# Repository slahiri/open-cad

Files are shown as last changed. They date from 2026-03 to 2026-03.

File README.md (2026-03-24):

# Protective Storage Box — Pelican/Gun Case Style

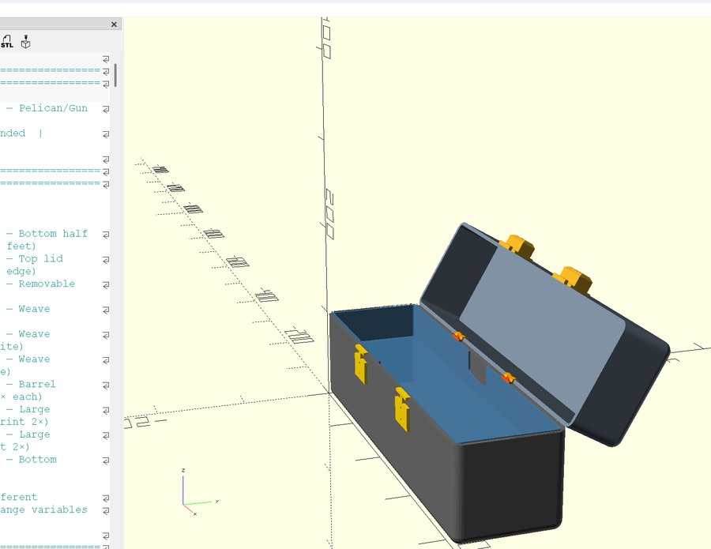
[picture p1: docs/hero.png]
Protective Storage Box


A 3D-printable protective storage box designed in OpenSCAD. Features a clamshell design with barrel hinges, butterfly latches, removable compartmented tray, and snap-fit 3-piece construction for printers with beds smaller than 420mm.

## Specifications

| Parameter | Value |
|---|---|
| Outer Dimensions | 420 x 110 x 160 mm |
| Wall Thickness | 4 mm |
| Bottom Height | 100 mm |
| Lid Height | 60 mm |
| Corner Radius | 10 mm (3D filleted) |
| Material | PETG recommended |

## Features

- Clamshell opening with 2 barrel hinges (M3 pin)
- 2 butterfly clamp latches (gun-box style)
- Removable interior tray (40mm) with finger notches
- Tray support ledge inside box walls
- Basket-weave lid insert (multi-color: white + blue)
- Gasket groove for weatherproofing (1mm silicone cord)
- 6 standoff feet with rubber pad recesses
- Split parts for printers with <420mm bed (e.g. Creality K2 Plus)

## Project Structure

```
open-cad/
  README.md
  .gitignore
  cad/                          # OpenSCAD source files
    protective_storage_box.scad   # Main library (all modules)
    view_closed.scad              # Assembly view: closed
    view_open.scad                # Assembly view: lid open
    view_open_tray_out.scad       # Assembly view: lid open, tray lifted
    stl_bottom_left.scad          # Export: box bottom left half
    stl_bottom_right.scad         # Export: box bottom right half
    stl_lid_left.scad             # Export: lid left half
    stl_lid_right.scad            # Export: lid right half
    stl_tray_left.scad            # Export: tray left half
    stl_tray_right.scad           # Export: tray right half
    stl_weave_frame_left.scad     # Export: weave frame left half
    stl_weave_frame_right.scad    # Export: weave frame right half
    stl_weave_x_left.scad         # Export: weave X-strips left (white)
    stl_weave_x_right.scad        # Export: weave X-strips right (white)
    stl_weave_y_left.scad         # Export: weave Y-strips left (blue)
    stl_weave_y_right.scad        # Export: weave Y-strips right (blue)
    stl_all_hardware.scad         # Export: hinges + latches on one plate
    export_k2plus.scad            # K2 Plus printing guide
    export_parts.scad             # Generic export guide
  stl/                          # Generated STL files (gitignored)
```

## How to Export STLs

Each `cad/stl_*.scad` file contains exactly one part. For each:

1. Open the file in OpenSCAD
2. **Design -> Render**
3. **File -> Export -> Export as STL**

## Print Settings (PETG)

| Part | Qty | Infill | Walls | Supports | Filament |
|---|---|---|---|---|---|
| Bottom L/R | 2 | 40% | 4 | No | Dark Gray |
| Lid L/R | 2 | 40% | 4 | No | Dark Gray |
| Tray L/R | 2 | 20% | 3 | No | Blue |
| Weave Frame L/R | 2 | 100% | 3 | No | Dark Gray |
| Weave X-strips L/R | 2 | 100% | 3 | No | White |
| Weave Y-strips L/R | 2 | 100% | 3 | No | Blue |
| Hardware | 1 plate | 60% | 4 | Yes | Black |

Nozzle: 245C | Bed: 80C | Speed: 50mm/s | Layer: 0.2mm (0.15mm for small parts)

## Hardware Required

- 8x M4x25mm bolts + nuts (joining halves)
- 12x M3x10mm screws (hinges + latches)
- 2x M3x25mm smooth rod (hinge pins)
- 6x rubber bumper pads 10mm
- ~1m silicone cord 1mm diameter

## Assembly

1. Bolt box bottom halves together (M4)
2. Bolt lid halves together (M4)
3. Glue tray halves
4. Glue weave halves together, press-fit into lid recess
5. Screw hinges to back wall, insert pin rods
6. Screw latches to front wall
7. Add rubber feet and gasket cord

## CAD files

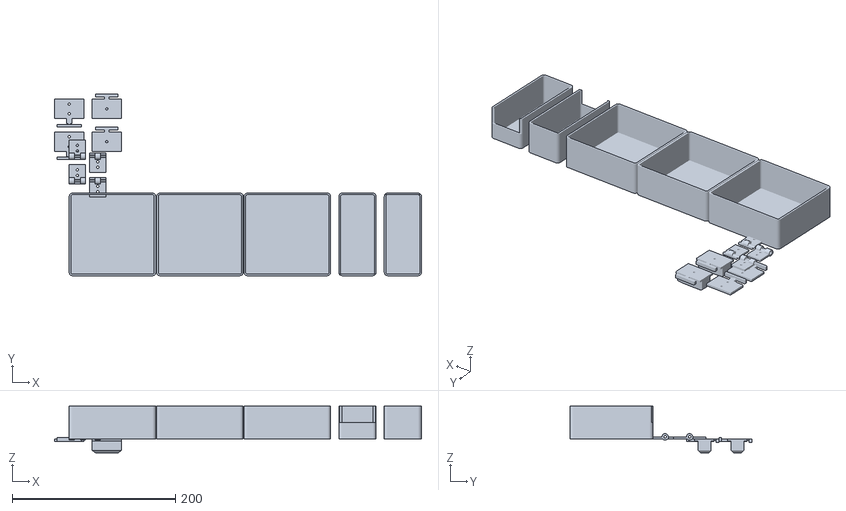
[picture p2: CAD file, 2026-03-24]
stl/parts/plate_small.stl
449.2 x 222.2 x 57.0

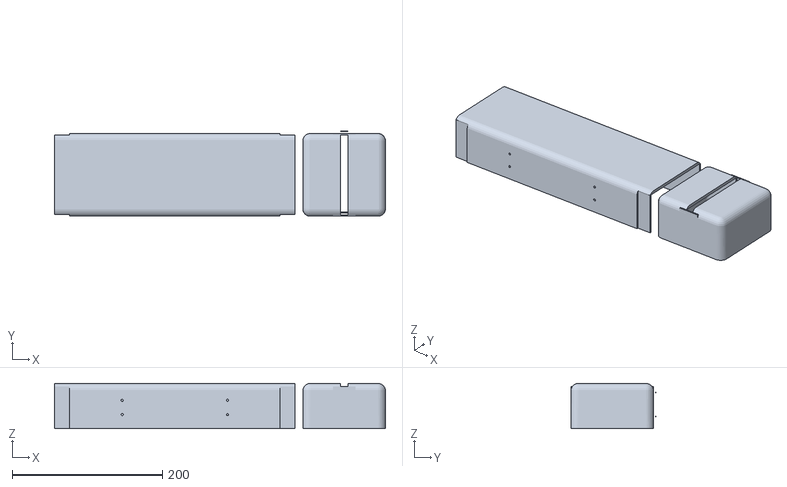
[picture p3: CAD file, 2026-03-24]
stl/parts/plate_lid.stl
440.0 x 113.6 x 59.9

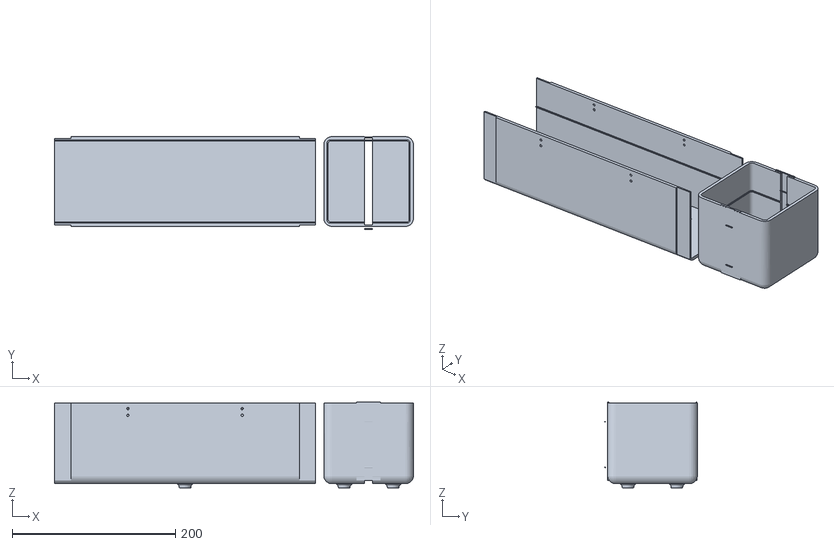
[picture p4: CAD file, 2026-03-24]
stl/parts/plate_box.stl
440.0 x 113.6 x 105.0

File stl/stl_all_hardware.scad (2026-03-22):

include <../cad/protective_storage_box.scad>
lid_angle = 0;
show_tray_in_assembly = false;
hinge_print_layout();
translate([0, 30, 0]) hinge_print_layout();
translate([0, 60, 0]) latch_print_layout();
translate([0, 100, 0]) latch_print_layout();

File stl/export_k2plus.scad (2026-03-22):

// ============================================================================
// CREALITY K2 PLUS — Multi-Color Export Guide
// ============================================================================
// Bed: 350×350×350mm  |  CFS: 4 filaments  |  Slicer: Creality Print / Orca
//
// WORKFLOW:
//   1. Uncomment ONE print plate section below
//   2. F6 (Render) → F7 (Export STL) for EACH color separately
//   3. Import all STLs for that plate into Creality Print as one project
//   4. Assign each STL to a filament slot (color)
//   5. Slice and print
//
// The box is 420mm — too long for 350mm bed.
// All box/lid/tray parts are SPLIT into left + right halves.
// Halves join with alignment pins + M4 bolts after printing.
//
// SUGGESTED 4 FILAMENT SLOTS:
//   Slot 1: Dark Gray PETG   (box body, lid, frame)
//   Slot 2: White PETG       (weave X-strips)
//   Slot 3: Blue PETG        (weave Y-strips, tray)
//   Slot 4: Black PETG       (latches, hinges)
// ============================================================================
include <../cad/protective_storage_box.scad>

// Override — don't render the default assembly
lid_angle = 0;
show_tray_in_assembly = false;
tray_lift = 0;

// ============================================================================
// PLATE 1: Box Bottom — Left Half
// Size: ~210×110×105mm  |  Color: Slot 1 (Dark Gray)
// Orientation: upright  |  Supports: NO  |  Infill: 40%  |  Walls: 4
// ============================================================================
//box_bottom_left();

// ============================================================================
// PLATE 2: Box Bottom — Right Half
// Size: ~210×110×105mm  |  Color: Slot 1 (Dark Gray)
// Orientation: upright  |  Supports: NO  |  Infill: 40%  |  Walls: 4
// ============================================================================
//box_bottom_right();

// ============================================================================
// PLATE 3: Box Lid — Left Half (FLIP in slicer: rotate 180° around X)
// Size: ~210×110×60mm  |  Color: Slot 1 (Dark Gray)
// Orientation: flip upside down  |  Supports: NO  |  Infill: 40%
// ============================================================================
//rotate([180, 0, 0]) translate([0, -width, -lid_h]) box_lid_left();

// ============================================================================
// PLATE 4: Box Lid — Right Half (FLIP in slicer: rotate 180° around X)
// Size: ~210×110×60mm  |  Color: Slot 1 (Dark Gray)
// Orientation: flip upside down  |  Supports: NO  |  Infill: 40%
// ============================================================================
//rotate([180, 0, 0]) translate([0, -width, -lid_h]) box_lid_right();

// ============================================================================
// PLATE 5: Tray — Left Half
// Size: ~206×102×40mm  |  Color: Slot 3 (Blue)
// Orientation: upright  |  Supports: NO  |  Infill: 20%  |  Walls: 3
// ============================================================================
//tray_left();

// ============================================================================
// PLATE 6: Tray — Right Half
// Size: ~206×102×40mm  |  Color: Slot 3 (Blue)
// Orientation: upright  |  Supports: NO  |  Infill: 20%  |  Walls: 3
// ============================================================================
//tray_right();

// ============================================================================
// PLATE 7: Weave Insert — MULTI-COLOR (3 STLs, same coordinates)
// ============================================================================
// Export EACH line below as a SEPARATE STL file, then import ALL THREE
// into Creality Print as one project. They will auto-align.
//
// Step 1: Uncomment lid_weave_frame(), render (F6), export as "weave_frame.stl"
// Step 2: Uncomment lid_weave_x_strips(), render, export as "weave_x_white.stl"
// Step 3: Uncomment lid_weave_y_strips(), render, export as "weave_y_blue.stl"
// Then in Creality Print: import all 3 → assign colors → slice
//
// Supports: NO  |  Infill: 100%  |  Layer: 0.15mm  |  Walls: 3
//
//lid_weave_frame();       // → Slot 1 (Dark Gray)
//lid_weave_x_strips();    // → Slot 2 (White)
//lid_weave_y_strips();    // → Slot 3 (Blue)

// ============================================================================
// PLATE 8: Hardware — Hinges × 2 + Latches × 2 (all Slot 4: Black)
// ============================================================================
// These are small enough to fit on one plate together.
// Supports: YES (auto)  |  Infill: 60%  |  Walls: 4  |  Layer: 0.15mm
//
// Hinge set 1
//hinge_print_layout();
// Hinge set 2
//translate([0, 30, 0]) hinge_print_layout();
// Latch set 1
//translate([0, 60, 0]) latch_print_layout();
// Latch set 2
//translate([0, 100, 0]) latch_print_layout();

// ============================================================================
// ALL HARDWARE ON ONE PLATE (uncomment this whole block)
// ============================================================================
/*
hinge_print_layout();
translate([0, 30, 0]) hinge_print_layout();
translate([0, 60, 0]) latch_print_layout();
translate([0, 100, 0]) latch_print_layout();
*/

// ============================================================================
// PRINT ORDER (recommended):
// ============================================================================
// 1. Plate 8  — Hardware (small, quick, test your settings)
// 2. Plate 7  — Weave insert (multi-color test)
// 3. Plates 5+6 — Tray halves (medium)
// 4. Plates 3+4 — Lid halves (large)
// 5. Plates 1+2 — Bottom halves (largest, longest print)
//
// ASSEMBLY AFTER PRINTING:
// 1. Join box bottom halves: insert alignment pins, secure with M4×25mm bolts
// 2. Join lid halves: same method
// 3. Join tray halves: glue with PETG-safe adhesive (or friction fit)
// 4. Press-fit weave strips into frame, insert into lid recess
// 5. Attach hinges to back wall with M3×10mm screws
// 6. Insert M3×25mm rod through hinge barrels
// 7. Attach latch bases to bottom front, levers to lid front
// 8. Glue rubber pads into standoff recesses
// 9. Press 1mm silicone cord into gasket groove
//
// HARDWARE SHOPPING LIST:
// - 4× M4×25mm bolts + nuts (joining box halves)
// - 4× M4×25mm bolts + nuts (joining lid halves)
// - 12× M3×10mm screws (hinges + latches)
// - 2× M3×25mm smooth rod or bolt (hinge pins)
// - 6× rubber bumper pads 10mm (standoff feet)
// - ~1m silicone cord 1mm diameter (gasket)
// - PETG adhesive / epoxy (tray halves)
// ============================================================================

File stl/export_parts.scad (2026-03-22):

// ============================================================================
// EXPORT HELPER — Single-color, generic printer
// ============================================================================
// For Creality K2 Plus multi-color, use export_k2plus.scad instead!
//
// Uncomment ONE part at a time, then:
//   F6 (Render) → F7 (Export STL)
// ============================================================================
include <../cad/protective_storage_box.scad>

lid_angle = 0;
show_tray_in_assembly = false;
tray_lift = 0;

// ---- FULL PARTS (need 420mm+ bed) ----
//box_bottom();
//rotate([180, 0, 0]) translate([0, -width, -lid_h]) box_lid();
//tray();
//lid_mesh_insert();

// ---- SPLIT PARTS (fits 350mm bed) ----
//box_bottom_left();
//box_bottom_right();
//rotate([180, 0, 0]) translate([0, -width, -lid_h]) box_lid_left();
//rotate([180, 0, 0]) translate([0, -width, -lid_h]) box_lid_right();
//tray_left();
//tray_right();

// ---- WEAVE (3 separate STLs for multi-color) ----
//lid_weave_frame();
//lid_weave_x_strips();
//lid_weave_y_strips();

// ---- HARDWARE ----
//hinge_print_layout();    // Print 2×
//latch_print_layout();    // Print 2×

// ---- ALL HARDWARE ON ONE PLATE ----
/*
hinge_print_layout();
translate([0, 30, 0]) hinge_print_layout();
translate([0, 60, 0]) latch_print_layout();
translate([0, 100, 0]) latch_print_layout();
*/

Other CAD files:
stl/stl_bottom_left.scad
cad/export_k2plus.scad
cad/export_parts.scad
cad/protective_storage_box.scad
cad/stl_bottom_left.scad
cad/stl_bottom_middle.scad
cad/stl_lid_middle.scad
cad/stl_lid_right.scad
cad/stl_plate_box.scad
cad/stl_plate_lid.scad
cad/stl_plate_small.scad
cad/stl_tray_middle.scad
cad/stl_tray_right.scad
cad/stl_weave_frame_right.scad
cad/stl_weave_x_left.scad
cad/stl_weave_y_left.scad
cad/view_closed.scad
cad/view_open.scad
cad/view_open_tray_out.scad
stl/stl_bottom_right.scad
stl/stl_lid_left.scad
stl/stl_lid_right.scad

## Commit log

2026-03-22 Initial commit: Pelican-style protective storage box (OpenSCAD)
    3D-printable gun case style box with barrel hinges, butterfly latches,
    removable tray, multi-color basket-weave lid insert, standoff feet,
    and split parts for 350mm bed printers (Creality K2 Plus).
    [export_k2plus.scad, export_parts.scad, protective_storage_box.scad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]
2026-03-24 Reorganize project: move scad to cad/, split weave parts, add lap joints and clamps
    - Move all .scad export files from stl/ to cad/ folder
    - Split weave insert into left/right halves to fit K2 Plus 350mm bed
    - Replace floating alignment pins + bolt holes with interlocking lap joints
    - Add printable snap-on clamp clips to join halves (no hardware needed)
    - Add render_assembly flag to suppress assembly in export files
    - Update batch export script to output to stl/parts/
    - Update README with new structure and assembly instructions
    [export_k2plus.scad, export_parts.scad, protective_storage_box.scad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]
2026-03-24 3-piece snap-fit design: 320mm middle + 50mm end caps, no hardware needed
    - Replace left/right split with 3-piece design (middle + 2 end caps)
    - Dovetail sleeve joints with snap-fit detents for tool-free assembly
    - Tray is now 5 independent compartments (3 middle + 2 end boxes)
    - Remove weave insert from lid and assembly (simplification)
    - 3 print plate STLs with proper spacing between parts
    - Remove old split/weave export files
    - Include generated STLs in repo
    [plate_box.stl, plate_lid.stl, plate_small.stl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]
